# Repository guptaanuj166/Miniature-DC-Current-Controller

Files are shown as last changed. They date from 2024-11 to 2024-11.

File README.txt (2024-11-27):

User manual:-  The document contains detailed info specifications, terminologies definitions, and instructions to use for the user along with additional instructions the user should take care of.

Design_documentation:- The document contains an overview of the project with the circuit as well as a block diagram. It also provides an overview of the CC-CV modes and control mechanisms.

PCB:- The directory contains .sch files which include schematic files and .pcb has placement and routing of components in the circuit.

CAD:- The directory contains all files for the final CAD assembly model of the project. It has mounting holes for wall attachment; each surface has groves for fitting a removable back panel structure.

Microcontroller_code:- The directory contains all code files of STM32 uC. The code contains a control algorithm for current, CC-CV mode transition, code for rotary encoder, hall-based current sensor to sense the current and setting reference voltage corresponding to current interfaces with DAC.

Test results:- The document includes test methodologies for the basic circuit, microcontroller integration, CC-CV switching and UART interfacing and the results of each methodology.

Frontend:- This contains python code for the web based GUI for UART control.

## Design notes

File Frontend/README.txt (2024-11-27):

For running the code, python is required.

Run the following line on a terminal:

pip install -r requirements.txt

Open serial_conn.py and change the COM port manually.

After this, 

streamlit run serial_conn.py

The current model doesn't account for the simultaneous use of read and write.

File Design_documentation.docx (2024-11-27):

Portable current indicator-cum-controller for panel mounting

Harish Mokashi Mayank Gupta Anuj Gupta Vansh Aggarwal

210070053@iitb.ac.in 210101002@iitb.ac.in 21d070014@iitb.ac.in 210070091@iitb.ac.in

Introduction

This is a lightweight, easy-to-use, accurate, current controller and indicator for researchers experimenting with electronics to obtain and control current values accurately, set manually or using a computer (UART). The voltage rating is 5V, and the current can be varied in the range 0-3A.

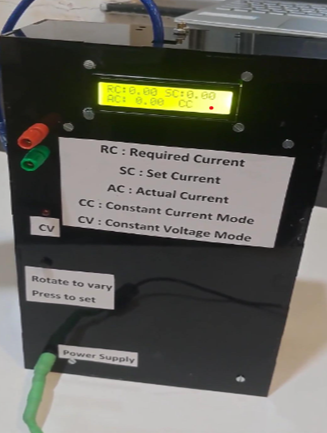
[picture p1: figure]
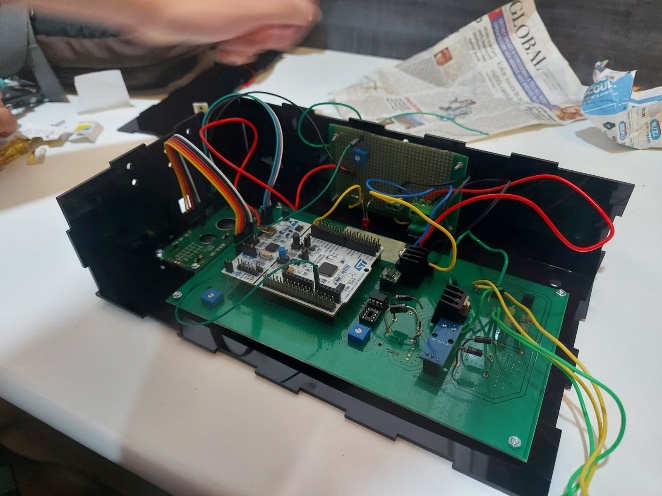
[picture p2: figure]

The components used:

- STM-32 microcontroller
- 2 TS912 opamps
- 2 TIP41C BJTs
- MCP4921 DAC
- ACS912 5A current sensor
- JHD162a 16 ×2 LCD display
- Rotary Encoder (pec12r-2220f-s0024)
- Power Resistors

The basic idea is to change the input voltage of opamps using a Digital-to-Analog converter operated using an STM-32 microcontroller. The output of each opamp drives a BJT to regulate the current. These two Opamp-BJT systems are connected in parallel; therefore, the actual current is the sum of currents from each BJT.

The user can set the current using either a rotary encoder or through UART from the laptop. The resulting current is displayed on the LCD or the laptop screen. Moreover, depending on the mode being constant current or constant voltage, an LED would remain off or on.

Below is the overall block diagram of our device:

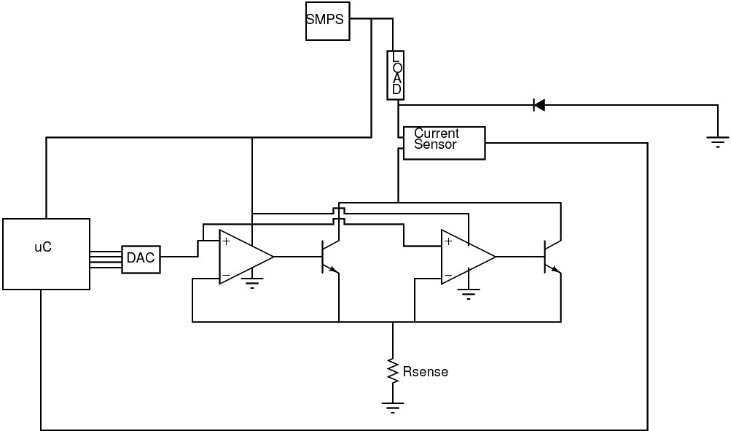
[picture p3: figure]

Below is the schematic of our circuit:

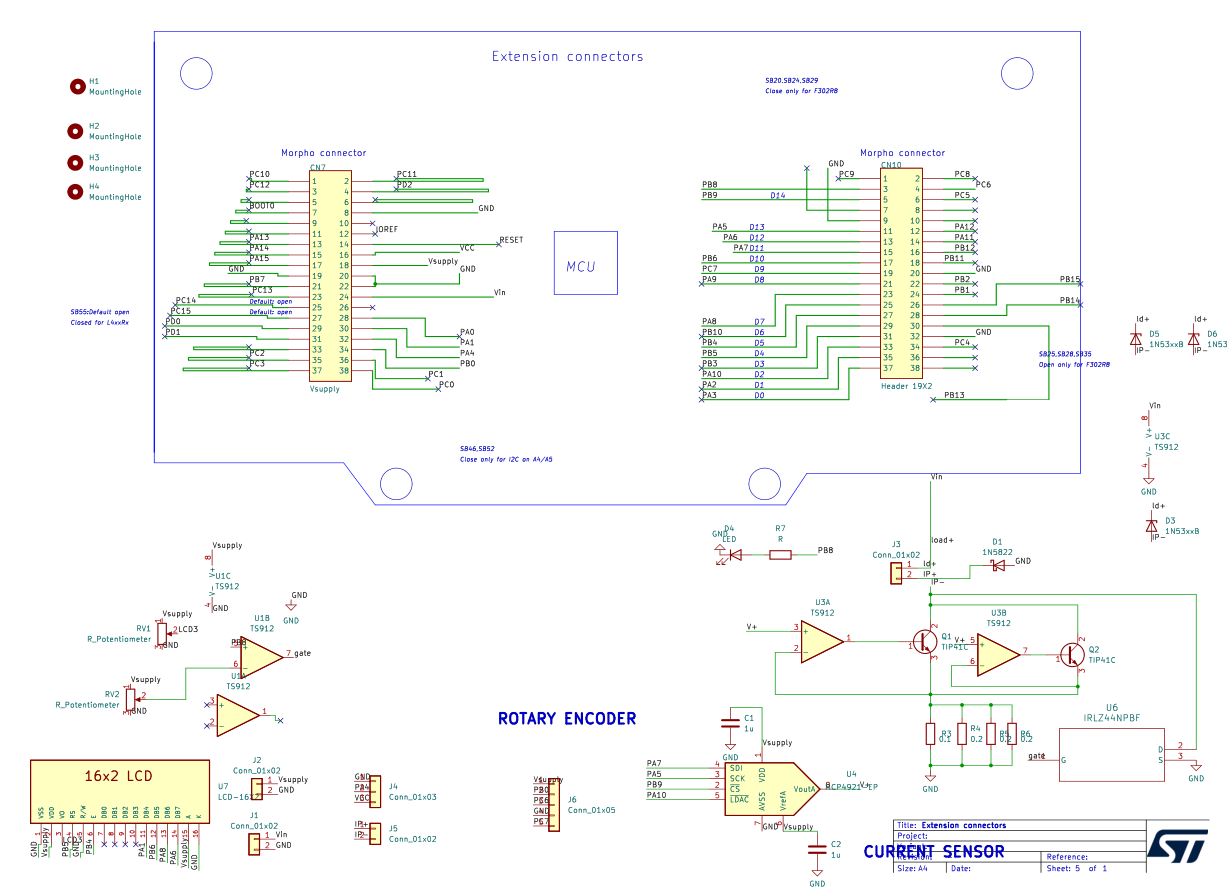
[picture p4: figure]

Modes of Operation

Our device has two modes of operation: constant voltage (CV) mode and constant current (CC) mode. Since the maximum voltage across the load is 5V, the maximum current the load can draw would be simply 5/R A, where R is the load resistance.
After setting the current, the device goes into CV mode if the set current is greater than the maximum current that can be drawn by the load; otherwise, it goes into CC mode and draws a current equal to the set current.

Control Mechanism

After pressing the rotary set button, the device goes into a transition phase where it employs a PD mechanism to converge to the required current.
When the device is in CV mode, the voltage across the load is also maintained at 5V using a PD control. The ADC of the STM32 reads the voltage value at the lower end of the load; the other end is connected to 9V input and tries to maintain it close to 4 V by varying the current across the load.

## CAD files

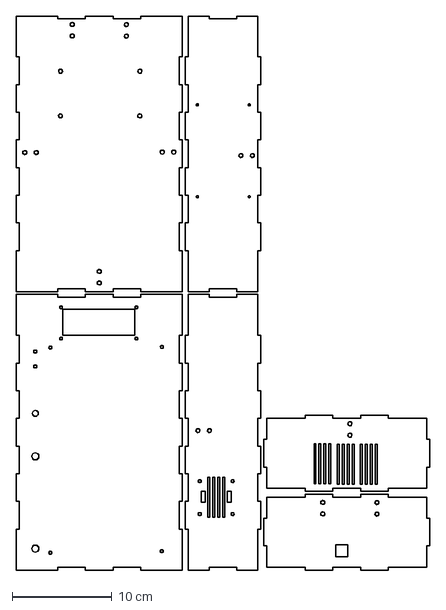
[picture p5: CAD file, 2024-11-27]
CAD/Laser_cut_box.dxf
41.4 x 55.5 cm

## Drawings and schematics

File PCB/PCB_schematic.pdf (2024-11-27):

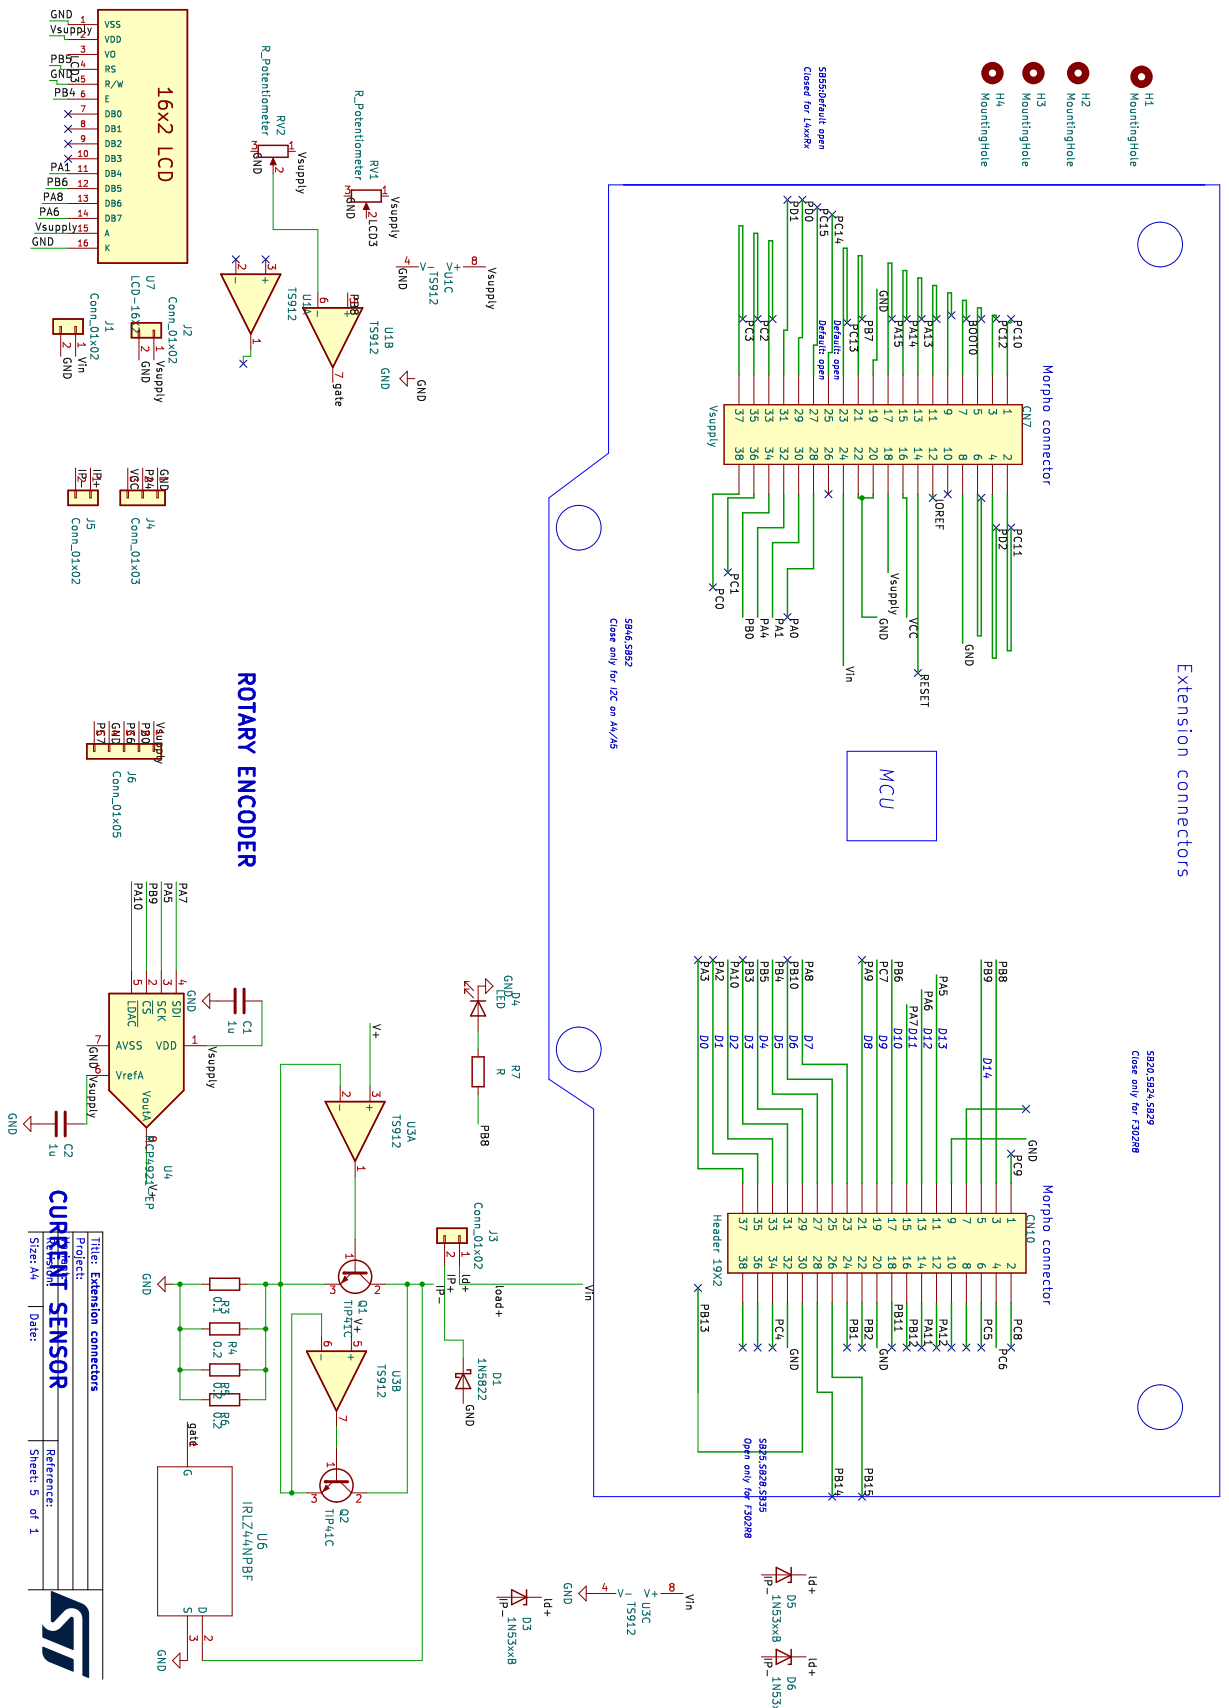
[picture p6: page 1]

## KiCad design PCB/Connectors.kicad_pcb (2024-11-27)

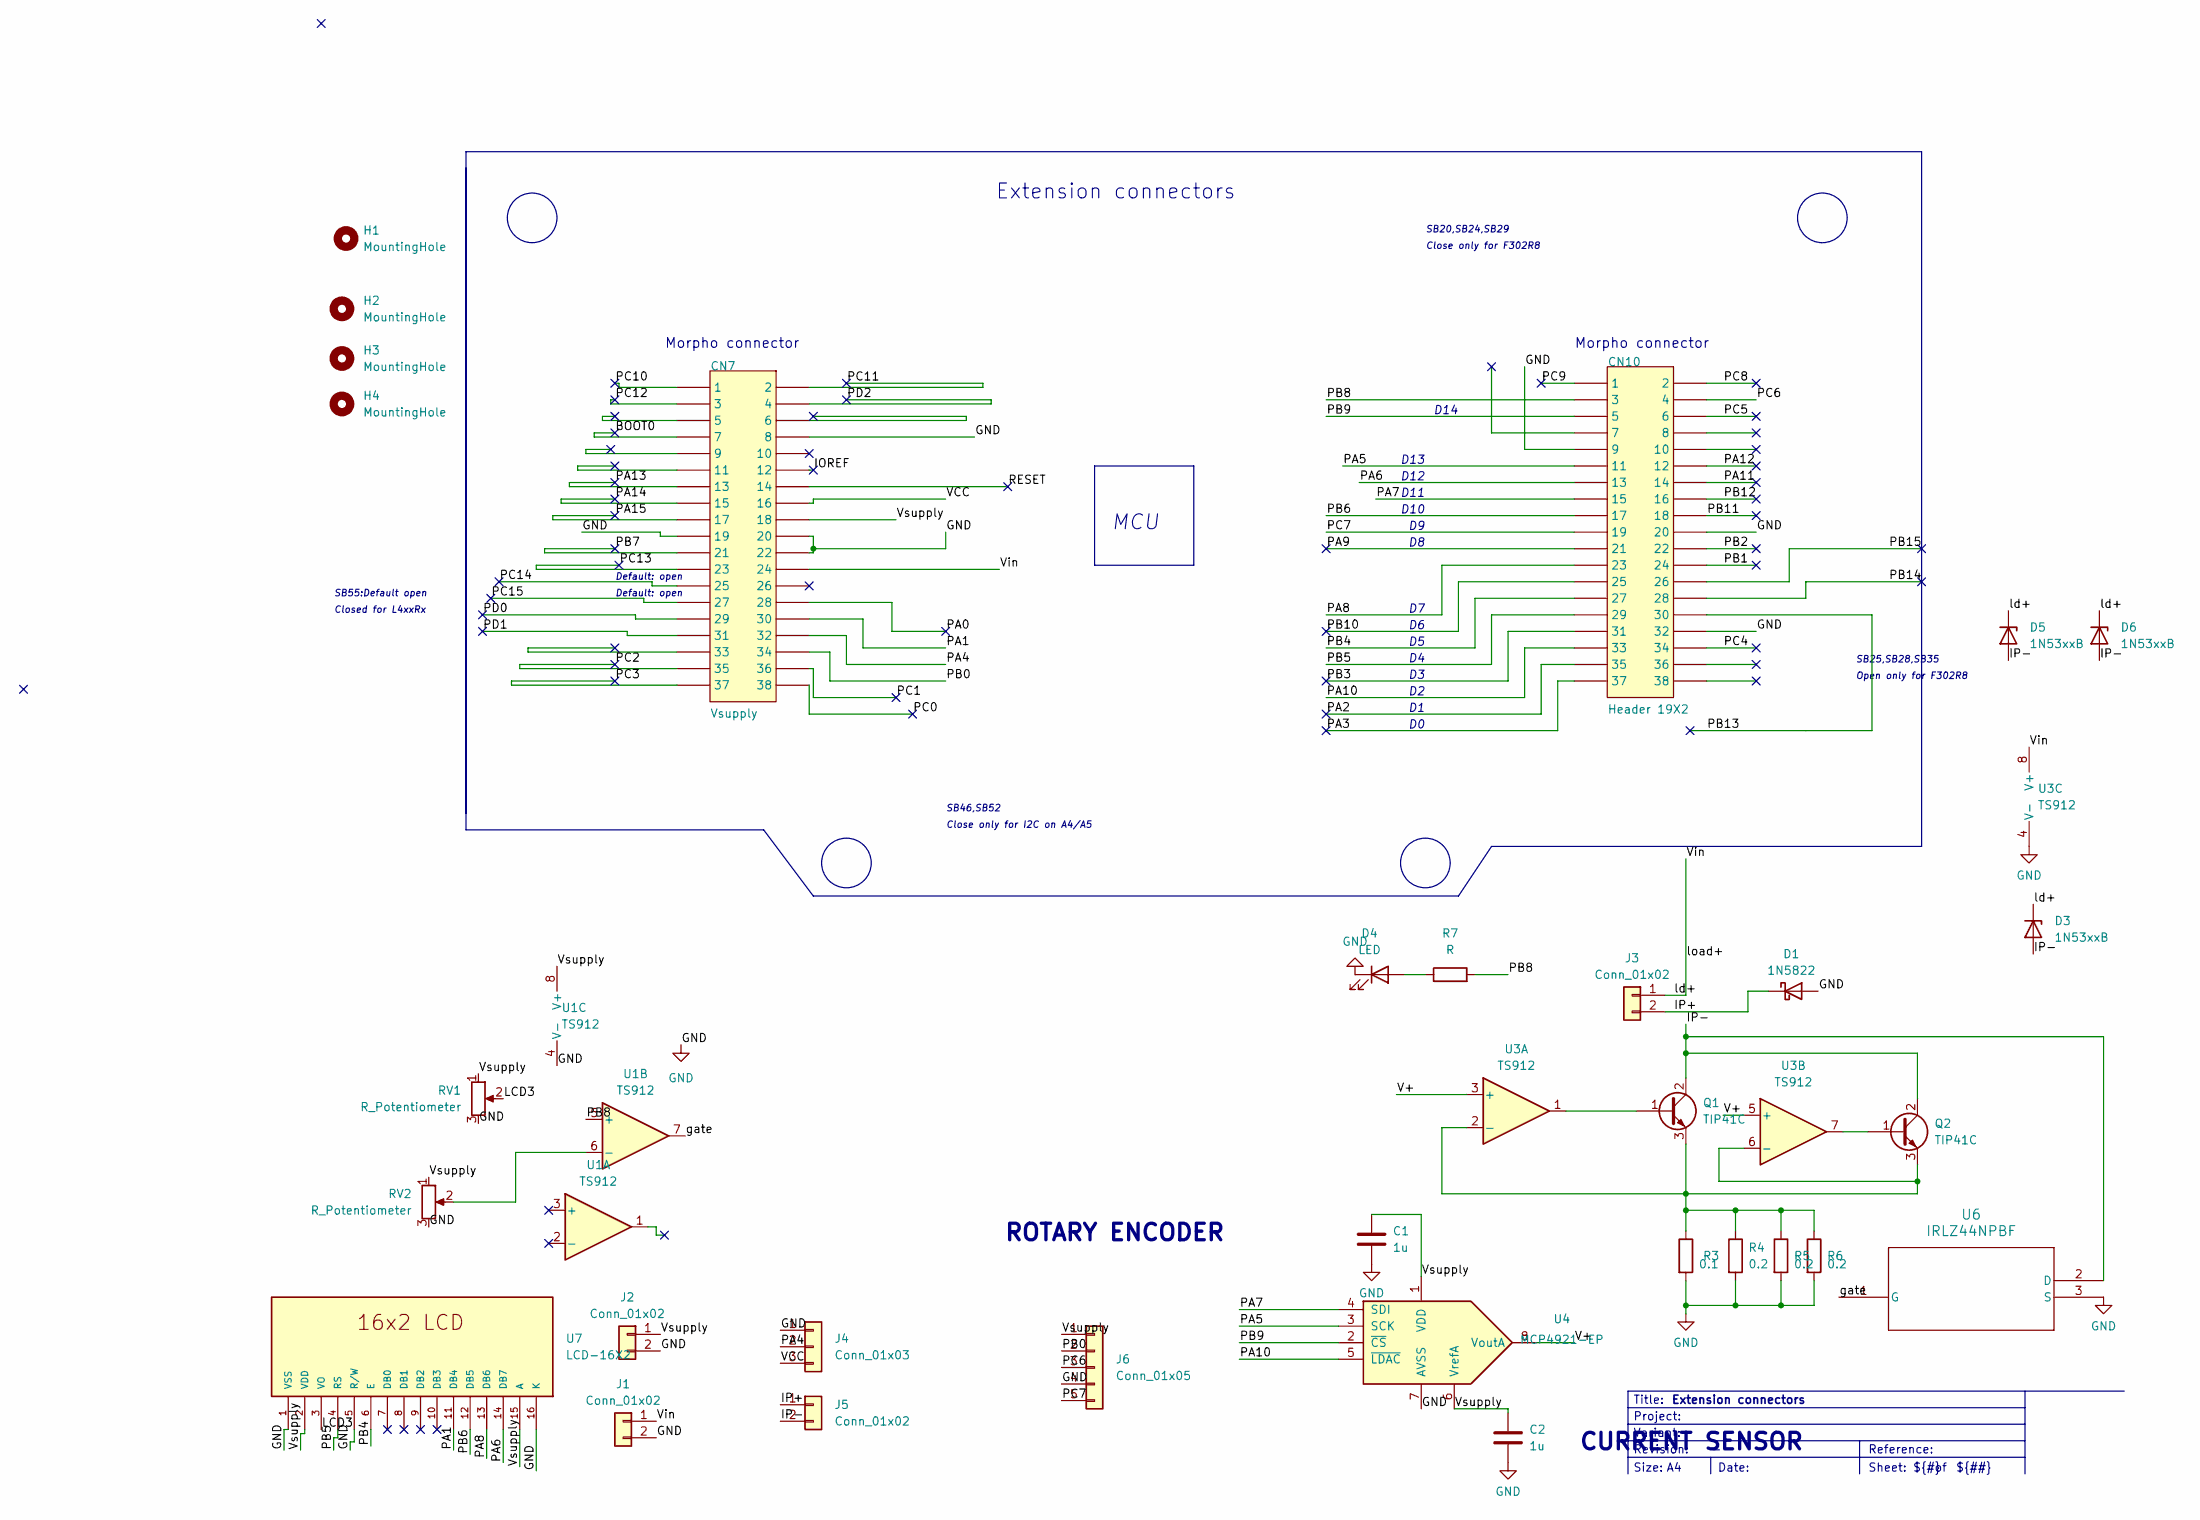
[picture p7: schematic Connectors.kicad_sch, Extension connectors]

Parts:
C1, C2: 1u; C_1206_3216Metric
CN7: Vsupply; PinSocket_2x19_P2.54mm_Vertical
CN10: Header 19X2; PinSocket_2x19_P2.54mm_Vertical
D1: 1N5822; D_DO-201AD_P15.24mm_Horizontal
D3, D5, D6: 1N53xxB; D_DO-201_P15.24mm_Horizontal
D4: LED; LED_1206_3216Metric
H1, H2, H3, H4: MountingHole; MountingHole_2.5mm
J1, J3: Conn_01x02; PinSocket_1x02_P2.54mm_Vertical
J2, J5: Conn_01x02; PinHeader_1x02_P2.54mm_Vertical
J4: Conn_01x03; PinSocket_1x03_P2.54mm_Vertical
J6: Conn_01x05; PinHeader_1x05_P2.54mm_Vertical
Q1, Q2: TIP41C; TO-220-3_Vertical
R3: 0.1; R_Axial_Power_L25.0mm_W9.0mm_P30.48mm
R4, R5, R6: 0.2; R_Axial_DIN0614_L14.3mm_D5.7mm_P25.40mm_Horizontal
R7: R; R_Axial_DIN0204_L3.6mm_D1.6mm_P7.62mm_Horizontal
RV1, RV2: R_Potentiometer; Potentiometer_Bourns_3386P_Vertical
U1, U3: TS912; TLV_bb
U4: MCP4921-EP; DIP-8_W7.62mm
U6: IRLZ44NPBF; PG-TO220-3_INF
U7: LCD-16X2; MODULE_LCD-16X2; PARTREV N/A

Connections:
/BOOT0: CN7.7
/IOREF: CN7.12
/IP+: D1.1 (K), J3.2, J5.1
/IP-: D3.2 (A), D5.2 (A), D6.2 (A), J5.2, Q1.2 (C), Q2.2 (C), U6.2 (D)
/LCD3: RV1.2, U7.3 (VO)
/PA0: CN7.28
/PA1: CN7.30, U7.11 (DB4)
/PA2: CN10.35
/PA3: CN10.37
/PA4: CN7.32, J4.2
/PA5: CN10.11, U4.3 (SCK)
/PA6: CN10.13, U7.14 (DB7)
/PA7: CN10.15, U4.4 (SDI)
/PA8: CN10.23, U7.13 (DB6)
/PA9: CN10.21
/PA10: CN10.33, U4.5 (~LDAC)
/PA11: CN10.14
/PA12: CN10.12
/PA13: CN7.13
/PA14: CN7.15
/PA15: CN7.17
/PB0: CN7.34, J6.2
/PB1: CN10.24
/PB2: CN10.22
/PB3: CN10.31
/PB4: CN10.27, U7.6 (E)
/PB5: CN10.29, U7.4 (RS)
/PB6: CN10.17, U7.12 (DB5)
/PB7: CN7.21
/PB8: CN10.3, R7.2, U1.5 (+)
/PB9: CN10.5, U4.2 (~CS)
/PB10: CN10.25
/PB11: CN10.18
/PB12: CN10.16
/PB13: CN10.30
/PB14: CN10.28
/PB15: CN10.26
/PC0: CN7.38
/PC1: CN7.36
/PC2: CN7.35
/PC3: CN7.37
/PC4: CN10.34
/PC5: CN10.6
/PC6: CN10.4, J6.3
/PC7: CN10.19, J6.5
/PC8: CN10.2
/PC9: CN10.1
/PC10: CN7.1
/PC11: CN7.2
/PC12: CN7.3
/PC13: CN7.23
/PC14: CN7.25
/PC15: CN7.27
/PD0: CN7.29
/PD1: CN7.31
/PD2: CN7.4
/RESET: CN7.14
/V+: U3.3 (+), U3.5 (+), U4.8 (VoutA)
/VCC: CN7.16, J4.3
/Vin: CN7.24, D3.1 (K), D5.1 (K), D6.1 (K), J1.1, J3.1, U3.8 (V+)
/Vsupply: C1.1, C2.1, CN7.18, J2.1, J6.1, RV1.1, RV2.1, U1.8 (V+), U4.1 (VDD), U4.6 (VrefA), U7.2 (VDD), U7.15 (A)
/gate: U1.7, U6.1 (G)
GND: C1.2, C2.2, CN7.8, CN7.19, CN7.20, CN7.22, CN10.9, CN10.20, CN10.32, D1.2 (A), D4.1 (K), J1.2, J2.2, J4.1, J6.4, R3.2, R4.2, R5.2, R6.2, RV1.3, RV2.3, U1.4 (V-), U3.4 (V-), U4.7 (AVSS), U6.3 (S), U7.1 (VSS), U7.5 (R/W), U7.16 (K)
unnamed: D4.2 (A), R7.1
unnamed: Q1.1 (B), U3.1
unnamed: Q1.3 (E), Q2.3 (E), R3.1, R4.1, R5.1, R6.1, U3.2 (-), U3.6 (-)
unnamed: Q2.1 (B), U3.7
unnamed: RV2.2, U1.6 (-)

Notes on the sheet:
SB20,SB24,SB29
Size:
${#}
Close only for I2C on A4/A5
Revision:
Morpho connector
CURRENT SENSOR
Close only for F302R8
D13
${##}
ROTARY ENCODER
D11
Extension connectors
Title:
Sheet:
Reference:
D10
Project:
Closed for L4xxRx
Default: open
MCU
Open only for F302R8
Variant:
Date:
SB55:Default open
${TITLE}
D14
SB46,SB52
D12
SB25,SB28,SB35

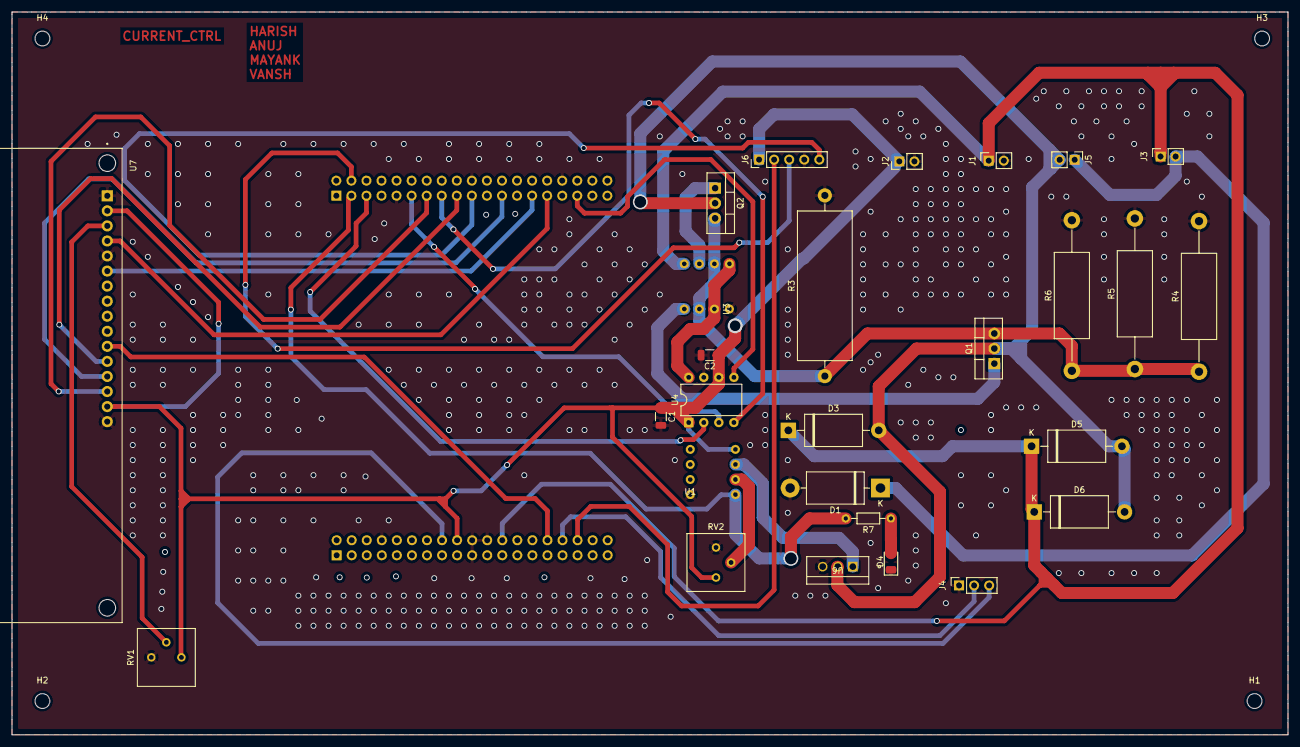
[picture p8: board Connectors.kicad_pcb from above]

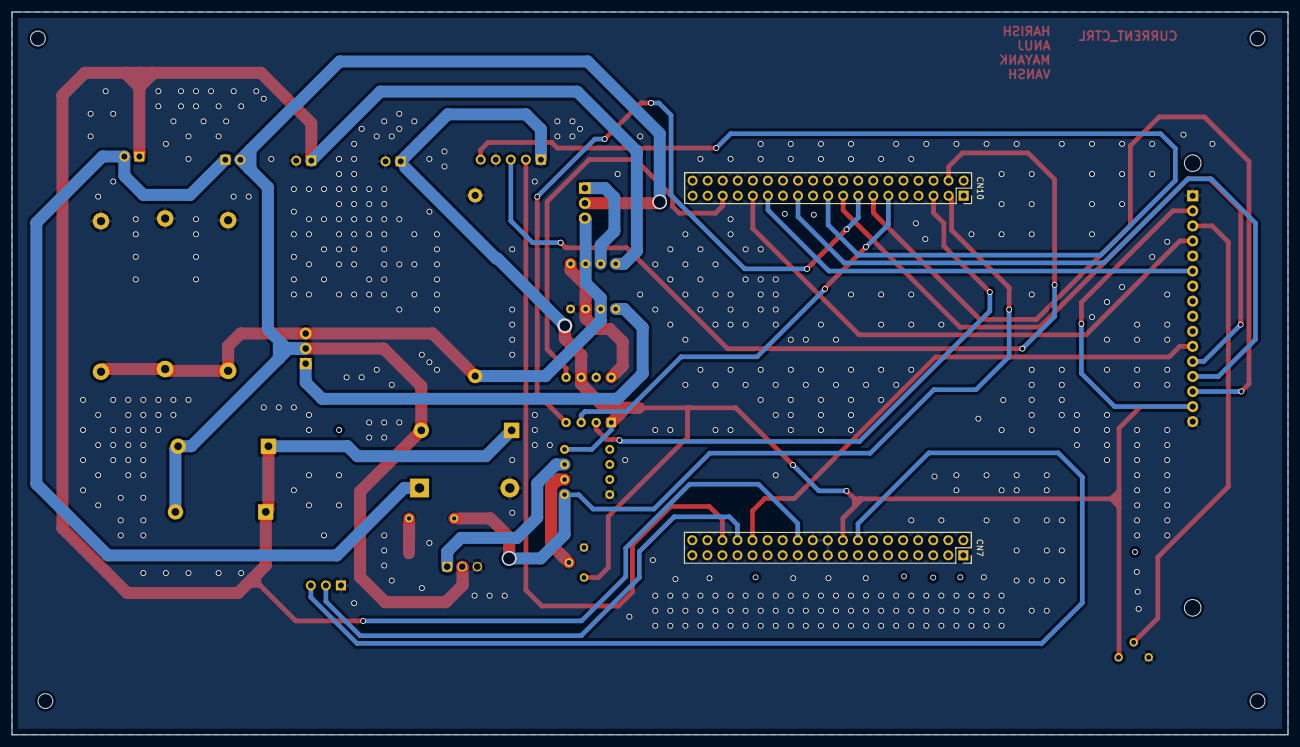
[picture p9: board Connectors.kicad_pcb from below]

Board: 2 copper layers, 215.2 x 121.9 mm, 33 parts (2 on the bottom side), 29 nets.

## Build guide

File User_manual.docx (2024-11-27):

User Manual

- Specifications

Supply Voltage (Vcc) | 6.7V – 10V (currently programmed for 9.2V)
DAC output voltage range | 0 – 5V
Output Current | 0 – 3A
Error | < 3.33% of Full Scale Range
Max Load Resistance | 50Ω
Compliance Voltage (Voltage output) | 5V
Precision | 100 mA
Settling Time | < 1s

- Terminologies

RC – Required Current – The current seen by the user upon varying the rotary encoder which will be set after pressing it.

SC – Set Current – The current limit set by the user.

AC – Actual Current – The actual current flowing through the load.

CC – Constant Current mode

CV – Constant Voltage mode

- Instructions to use
1. Plug the DC power supply to power the device.
2. Attach the load to the load terminals.
3. Set the current using either a rotary encoder or from a laptop using UART.
4. For the rotary encoder, turn the rotary encoder till RC displays the maximum current required, then press the rotary encoder to set the current.
5. Observe the current on the LCD.
- Additional Instructions:
1. The rotary encoder is circularly encoded, which means that if you turn left from 0 A, you can easily reach 3A.
2. Always use power resistances, not the normal resistances available in the lab. Keep the load rating below the value specified; otherwise, voltage readings will get distorted because of low current.
3. This is specifically designed for high power loads, implying a high current and a low resistance.
4. The equipment is safe for the use of any load below the specified limit, implying it is robust to short circuits also.
5. It is not heat tested as of now, which means that do not allow high currents to flow for more than 6-7 hours.

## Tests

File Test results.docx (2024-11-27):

Important test results and final testing outcomes

1. Basic Circuit
  1.1. Initially, we started by directly giving a voltage, controlled by a potentiometer, to the non-inverting input of the op-amp, with the op-amp output connected to the gate of an NMOS transistor (using a single circuit). For the circuit diagram, refer to the design documentation.
  1.2. We noted that the current was varying over a small voltage range, due to the quadratic characteristics of MOSFETs. This made it difficult to have fine control over the current value.
  1.3. Because of this, we moved towards BJT. Here, we observed that the maximum value of current reached was ~ 2.5A. So, we decided to have two circuits in parallel.
2. Integrating with microcontroller
  2.1. Then, we gave the non-inverting voltage through a DAC controlled by an STM microcontroller.
  2.2. This required some fine-tuning of the parameters in the microcontroller code.
3. CC-CV switching
  3.1. For CC-CV switching, we first tried implementing a switch using an MOS transistor. This malfunctioned in our fabricated PCB.
  3.2. Then, we used current control to maintain constant compliance voltage across the load in CV mode.
4. Implementing UART
  4.1. We also included control of current using UART.
  4.2. This can accurately read and write the current values.

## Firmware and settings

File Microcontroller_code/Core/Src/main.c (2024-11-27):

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
/* Includes ------------------------------------------------------------------*/
#include "main.h"

/* USER CODE BEGIN Includes */
#include "lcd.h"
#include <stdio.h>
/* USER CODE END Includes */

ADC_HandleTypeDef hadc1;
ADC_HandleTypeDef hadc2;

SPI_HandleTypeDef hspi1;

TIM_HandleTypeDef htim3;

UART_HandleTypeDef huart2;

/* USER CODE BEGIN PV */
uint8_t  rx_indx, rx_data[6], rx_buffer[100], transfer_cplt, val_f=0, wr_f=0;
/* USER CODE END PV */

void SystemClock_Config(void);
static void MX_GPIO_Init(void);
static void MX_ADC1_Init(void);
static void MX_SPI1_Init(void);
static void MX_TIM3_Init(void);
static void MX_USART2_UART_Init(void);
static void MX_ADC2_Init(void);
/**
  * @brief  The application entry point.
  * @retval int
  */
int main(void)
{
	/* MCU Configuration--------------------------------------------------------*/

	/* Reset of all peripherals, Initializes the Flash interface and the Systick. */
	HAL_Init();

	/* Configure the system clock */
	SystemClock_Config();

	/* Initialize all configured peripherals */
	MX_GPIO_Init();
	MX_ADC1_Init();
	MX_SPI1_Init();
	MX_TIM3_Init();
	MX_USART2_UART_Init();
	MX_ADC2_Init();

	Lcd_PortType ports[] = { GPIOA, GPIOB, GPIOA, GPIOA };
	Lcd_PinType pins[] = {GPIO_PIN_1, GPIO_PIN_6, GPIO_PIN_8, GPIO_PIN_6};
	Lcd_HandleTypeDef lcd;

	lcd = Lcd_create(ports, pins, GPIOB, GPIO_PIN_5, GPIOB, GPIO_PIN_4, LCD_4_BIT_MODE);
	Lcd_clear(&lcd);
	Lcd_cursor(&lcd, 0,0);


	uint8_t var1=0x33, var2=0xFF; // Two 8 bit variables to send SPI for DAC, Initial 4 bits are always fixed, make sure to look at datasheet
	uint16_t current_v=0,adc_val=0,counter=0, voltage=0;
	uint32_t Samples=0;
	float current_reading, current_set=0, p_err=0, current_avg=0, c=0, current_sum=0;
	uint8_t var[2]={var1,var2}, count2=0, f=0, cv_flag=0, kp=21;

	HAL_GPIO_WritePin(GPIOB, GPIO_PIN_8, GPIO_PIN_RESET); // Initialize LED to OFF

	HAL_TIM_Encoder_Start_IT(&htim3, TIM_CHANNEL_ALL);
	HAL_UART_Receive_IT(&huart2, rx_data, 1);


	while (1)
	{

		Lcd_cursor(&lcd, 0,0);
		Lcd_string(&lcd, "RC:");
		// Rotary turn
		counter=TIM3->CNT; // Rotary encoder is just counter in encoder mode for turns, check rotary data sheet for better understanding

		Lcd_cursor(&lcd, 0,3);
		Lcd_float(&lcd, 1.0*counter/100);

		// Detect rotary press
		if(HAL_GPIO_ReadPin(GPIOB, GPIO_PIN_0) == GPIO_PIN_SET){
			current_set=0.01*counter;
			//Average resistance is different for each current range
			if (current_set<1.1)
				current_v=4095*12*current_set/500;
			else if (current_set<2.1)
				current_v=4095*11*current_set/500;
			else
				current_v=4095*10*current_set/500;
		}


		Lcd_cursor(&lcd, 0,8);
		Lcd_string(&lcd, "SC:");
		Lcd_cursor(&lcd, 0,11);
		Lcd_float(&lcd, current_set);

		// Reading of potential for current from Hall Based sensor
		Samples=0;
		for (int x = 0; x < 150; x++){ //Get 150 samples
			HAL_ADC_Start(&hadc1);
			HAL_ADC_PollForConversion(&hadc1,20);
			adc_val = HAL_ADC_GetValue(&hadc1);    //Read current sensor values
			HAL_ADC_Stop(&hadc1);
			Samples = Samples + adc_val;  //Add samples together
		}
		adc_val=Samples/150;//Taking Average of Samples

		if (current_set<1.5)
			current_reading=(-adc_val*3.42/4036+1.669)/0.084; // Equation is based on sensitivity and trial & error
		else
			current_reading=(-adc_val*3.0/4095+1.442)/0.084;

		if (current_reading<0){
			current_reading=0;
		}


		// PD controller for both CC and CV
		if (cv_flag==1){
			if ((voltage>1700)|| (voltage<1600))
				kp=10;
			else
				kp=1;

			if ((voltage>1645))
				current_v=current_v+kp;

			else if ((voltage<1645)){
				if (current_v > kp)
					current_v=current_v-kp;
			}
		}
		else{
			if (current_reading-current_set > 0.05){
				if (current_v > 3)
					current_v=current_v-3+0*(current_reading-current_set -p_err);
			}
			else if(current_reading-current_set < 0.05){

				current_v=current_v+3+0*(current_reading-current_set -p_err);
			}
			p_err=current_reading-current_set;
		}

		// Transition condition (0.1 A is the accuracy)
		Lcd_cursor(&lcd, 1,10);
		if (((current_reading+0.1>current_set) && ((voltage>1750) || ((voltage<10) ||current_set<0.08))) || ((f==0) && (count2<41)) )
		{ //CC
			HAL_GPIO_WritePin(GPIOB, GPIO_PIN_8, GPIO_PIN_RESET);

			Lcd_string(&lcd, "CC");
			count2++;
			f=0;
			if (cv_flag==1){
				if (current_set<1.1)
					current_v=4095*12*current_set/500;
				else if (current_set<2.1)
					current_v=4095*11*current_set/500;
				else
					current_v=4095*10*current_set/500;
				cv_flag=0;
			}

		}
		else if(count2==0 || count2>40)
		{//CV

			HAL_GPIO_WritePin(GPIOB, GPIO_PIN_8, GPIO_PIN_SET);

			Lcd_string(&lcd, "CV");
			count2=0;
			f=1;
			cv_flag=1;
		}

		//Measuring potential of lower end of load scaled to 3.3V for ADC, upper end is always 9V
		Samples=0;
		for (int x = 0; x < 150; x++){ //Get 150 samples
			HAL_ADC_Start(&hadc2);
			HAL_ADC_PollForConversion(&hadc2,20);
			adc_val = HAL_ADC_GetValue(&hadc2);    //Read potential values
			HAL_ADC_Stop(&hadc2);
			Samples = Samples + adc_val;  //Add samples together
		}
		adc_val=Samples/150;//Taking Average of Samples
		voltage=adc_val;
		if (current_set==0.00)
			current_v=0;
		if (current_v > 320) // Value of potential (in digital) above which no value would ever be required for any kind of load, thus limiting it to prevent any garbage value
			current_v=320;

		// Transmission to DAC using SPI
		var2=current_v&0xFF;
		var1=current_v/256;

		var1=var1&0x0F;
		var1=var1|0x30;
		var[0]=var1;
		var[1]=var2;
		Lcd_cursor(&lcd, 1,0);
		Lcd_string(&lcd, "AC:");
		Lcd_cursor(&lcd, 1,4);

		// Displaying avg current in some cases to prevent fluctuations
		current_sum=current_reading+current_sum;
		if (c==9){
			current_avg=current_sum/10;
			c=0;
			current_sum=0;
		}
		if (current_avg==0)
			current_avg=current_reading;
		c++;

		if ((current_avg>current_set+0.1) || (current_avg+0.1<current_set) || (!current_reading))
			Lcd_float(&lcd, current_reading);
		else
			Lcd_float(&lcd, current_avg);

		// Transmiting to DAC
		HAL_GPIO_WritePin(GPIOA, GPIO_PIN_10, GPIO_PIN_SET); //LDAC_bar is set while transmission
		HAL_GPIO_WritePin(GPIOB, GPIO_PIN_9, GPIO_PIN_RESET); //CS_bar is transitioned to 0 just before transmission starts (falling edge)
		HAL_SPI_Transmit(&hspi1, var, 2, 100); //Higher byte with 1st nibble as the config bits, 2nd one is the data

		HAL_GPIO_WritePin(GPIOB, GPIO_PIN_9, GPIO_PIN_SET); //CS_bar rising edge to signify end of transmission of data
		HAL_GPIO_WritePin(GPIOA, GPIO_PIN_10, GPIO_PIN_RESET); // LDAC_bar falling edge when not transmitting


		// UART (There is a function near the end of the, RxCplt check that out for more details)
		uint8_t Test[]={48,46,48,48, '\n', '\r'}; //Data to send
		if (val_f==1){
			// Converting numbers to ASCII
			Test[0]=48+current_reading/10*10;
			Test[2]=(10*current_reading);
			Test[2]=48+Test[2]%10;
			Test[3]=100*current_reading;
			Test[3]=48+Test[3]%10;
			HAL_UART_Transmit(&huart2,Test,sizeof(Test),10);
		}

		if ((wr_f==1) && (transfer_cplt==1)){
			// ASCII to numbers
			float c_set_dummy;
			c_set_dummy=(rx_buffer[0]-48)*100+(rx_buffer[2]-48)*10+(rx_buffer[3]-48);
			transfer_cplt=0;
			if ((rx_buffer[0]<52) && (rx_buffer[0]>47) && (rx_buffer[2]>47) && (rx_buffer[3]>47)){
				current_set=c_set_dummy;

				current_set=0.01*(current_set);

				if (current_set<1.1)
					current_v=4095*12*current_set/500;
				else if (current_set<2.1)
					current_v=4095*11*current_set/500;
				else
					current_v=4095*10*current_set/500;
			}

		}


	}
  /* USER CODE END 3 */
}

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
/* USER CODE BEGIN 4 */
void HAL_UART_RxCpltCallback(UART_HandleTypeDef *huart){
	HAL_UART_Receive_IT(&huart2, rx_data, 1);
//	HAL_UART_Transmit(&huart2, rx_data, 6, 100);
	if (rx_indx==0){
		uint8_t i=0;
		for (i=0; i<100; i++){
			rx_buffer[i]=0;
		}
	}

	if (rx_data[0] != 13){ // 13 is newline character (\r)
		rx_buffer[rx_indx++]= rx_data[0];
	}
	else{
		rx_indx=0;
		transfer_cplt=1;
		HAL_UART_Transmit(&huart2, "\r\n", 2, 100);
		if (!strcmp(rx_buffer, "read")){
			val_f=1;
		}
		else if (!strcmp(rx_buffer, "stop read")){
			val_f=0;
		}
		else if (!strcmp(rx_buffer, "write")){
			wr_f=1;
			uint8_t i=0;
			for (i=0; i<100; i++){
				rx_buffer[i]=0;
			}
			// making it 0.00 when write was typed to prevent setting ascii of "write" as the current
			rx_buffer[0]=48;
			rx_buffer[1]=46;
			rx_buffer[2]=48;
			rx_buffer[3]=48;

		}
		else if (!strcmp(rx_buffer, "stop write")){
			wr_f=0;
		}
	}



}
/* USER CODE END 4 */
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


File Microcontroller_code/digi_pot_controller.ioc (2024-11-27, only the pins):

Mcu.UserName=STM32F103RBTx
PA0-WKUP.Signal=ADCx_IN0
PA1.Signal=GPIO_Output
PA10.Signal=GPIO_Output
PA2.Signal=USART2_TX
PA3.Signal=USART2_RX
PA4.Signal=ADCx_IN4
PA5.Signal=SPI1_SCK
PA6.Signal=GPIO_Output
PA7.Signal=SPI1_MOSI
PA8.Signal=GPIO_Output
PB0.Signal=GPIO_Input
PB4.Signal=GPIO_Output
PB5.Signal=GPIO_Output
PB6.Signal=GPIO_Output
PB8.Signal=GPIO_Output
PB9.Signal=GPIO_Output
PC6.Signal=S_TIM3_CH1
PC7.Signal=S_TIM3_CH2

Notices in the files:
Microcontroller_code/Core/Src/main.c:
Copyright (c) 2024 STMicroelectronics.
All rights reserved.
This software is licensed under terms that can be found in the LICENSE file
